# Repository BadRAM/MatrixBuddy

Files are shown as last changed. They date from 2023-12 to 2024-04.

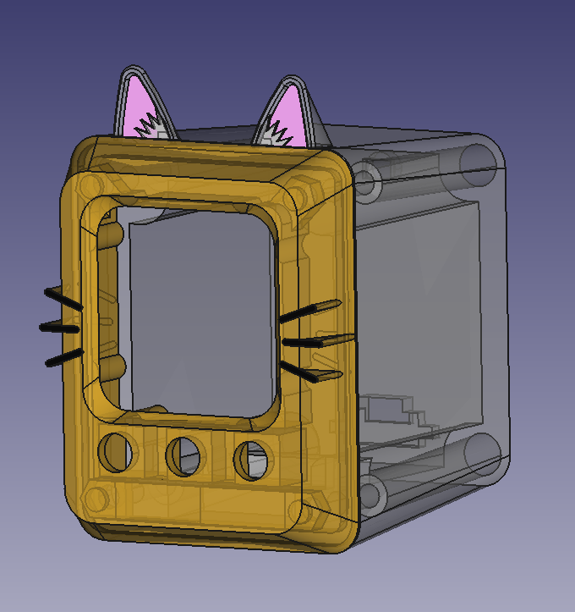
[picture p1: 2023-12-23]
Printing/MatrixBuddyCAD.png

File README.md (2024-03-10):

A friend shaped device, using a MAX7219 driven LED matrix.

[Video Demonstration](https://www.youtube.com/watch?v=6w6y-6xS34Q)

Features:
 - Matrix Buddy posesses the GREAT EMOTIONAL STRENGTH to grin through any mood, should you need TOTAL AFFIRMATION. Press the bell to toggle, Buddy will wink to acknowledge, or blink when it is released.
 - Worried about light pollution? Matrix Buddy can read the room! Sleep mode activates in near darkness. Press the left paw to configure it's light threshold. The light sensor is on the back, make sure it's not covered.
 - Not light polluted enough? Press the right paw to configure brightness. Unleash the power of the sun!
 - Connect to a computer using the bridge program and matrix buddy can mouth along to your apps. Give a face to that cameras-off zoom call!

 To set up the Matrix Buddy Bridge app, you will first need to install the included serial drivers (CM212364_Setup.exe) and restart your computer. Run MatrixBuddyBridge.exe and press "Scan", if a device is found, you're ready, just uncheck "Mute" when you're ready for the buddy to start.

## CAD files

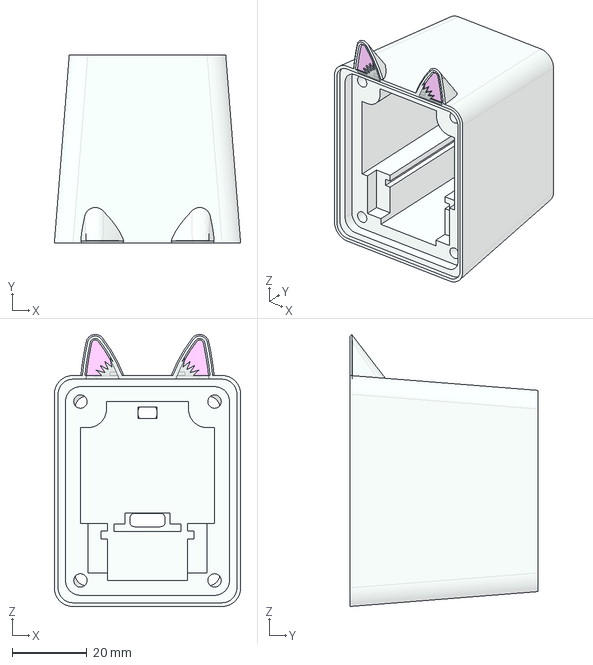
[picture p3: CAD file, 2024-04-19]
Printing/MatrixBuddy-Shell.step
50.0 x 50.5 x 73.0 mm
EarColor001
Main002

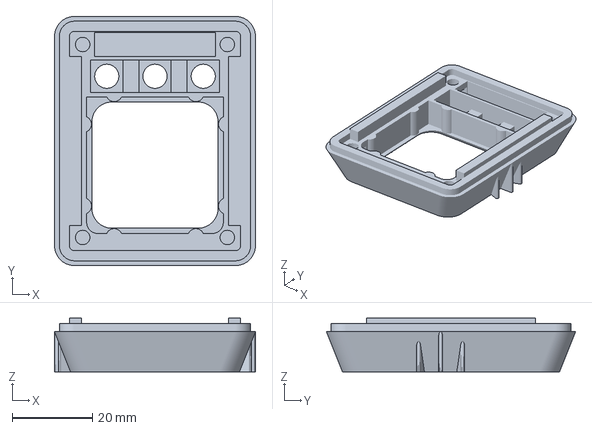
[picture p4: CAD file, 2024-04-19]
Printing/MatrixBuddyFace.3mf
50.0 x 62.0 x 13.4 mm

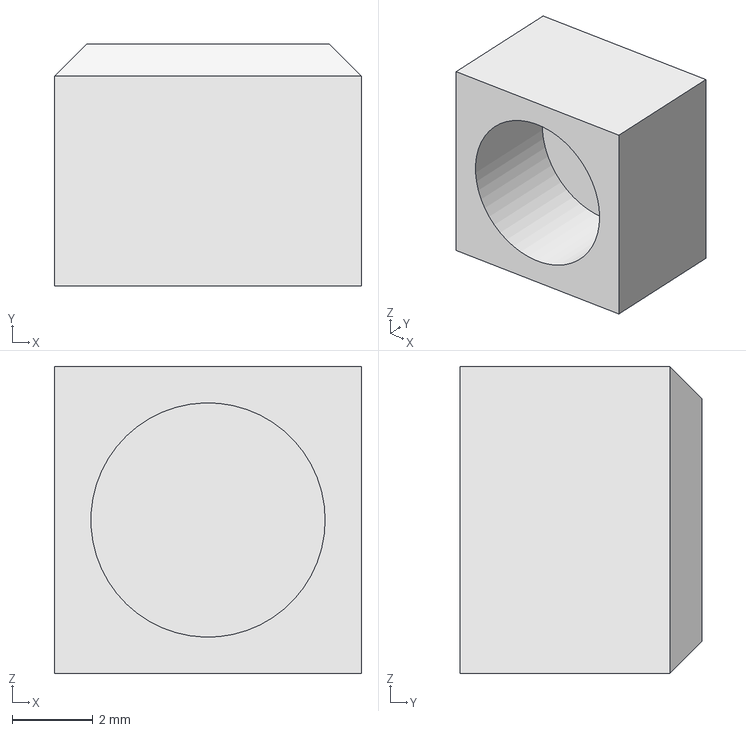
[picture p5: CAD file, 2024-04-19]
Printing/MatrixBuddy-ButtonBack.step
7.60 x 6.00 x 7.60 mm

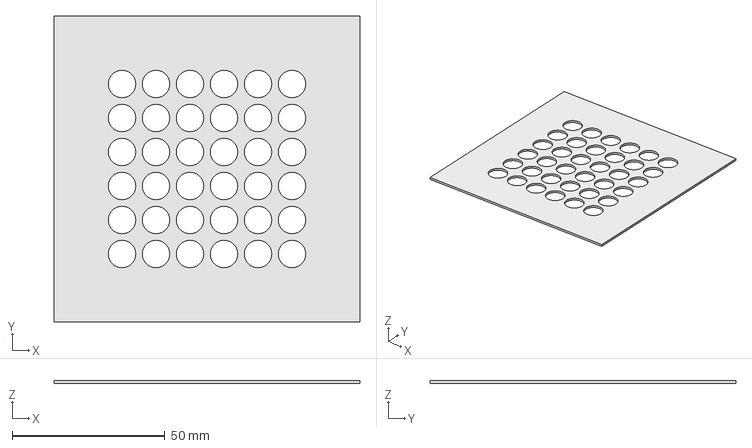
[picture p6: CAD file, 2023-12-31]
Printing/MatrixBuddy-BoxStencilCirclesStencil.step
100.0 x 100.0 x 1.00 mm

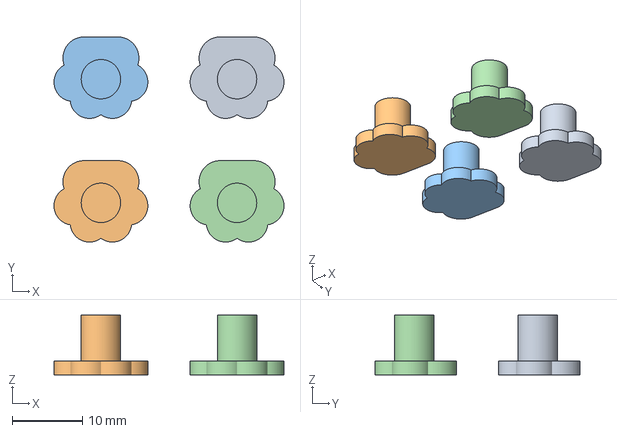
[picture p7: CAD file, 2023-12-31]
Printing/MatrixBuddyPaws.3mf
32.7 x 29.1 x 8.50 mm

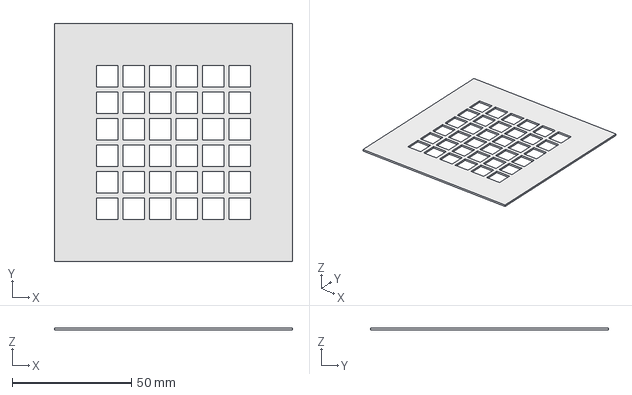
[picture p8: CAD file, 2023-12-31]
Printing/MatrixBuddy-BoxStencilSquareStencil.step
100.0 x 100.0 x 1.00 mm

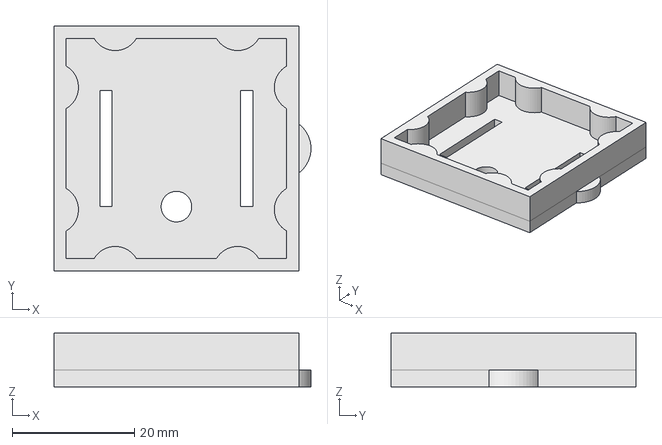
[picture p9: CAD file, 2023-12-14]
Printing/MatrixBuddy-ClippingJig.step
42.0 x 40.0 x 8.80 mm

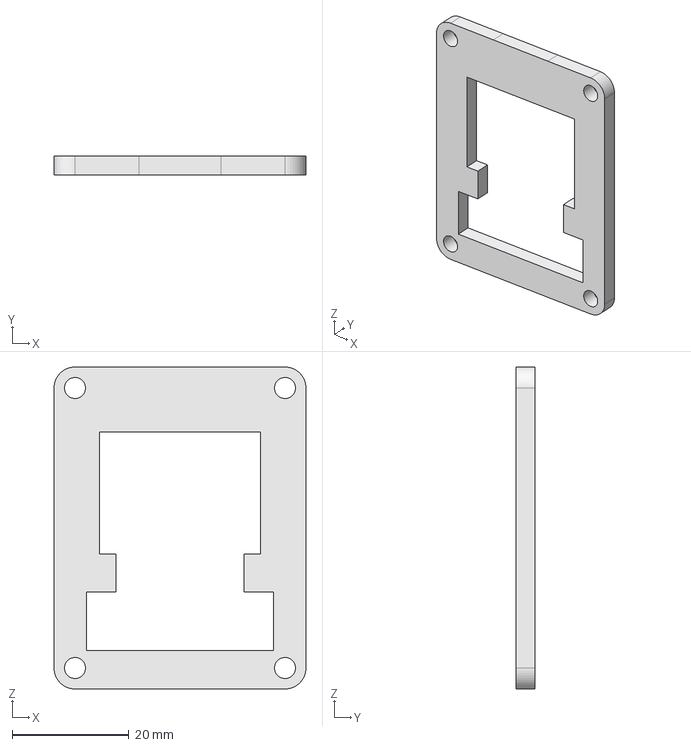
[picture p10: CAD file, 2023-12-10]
Printing/MatrixBuddy-FacerSpacer.step
43.2 x 3.20 x 55.2 mm

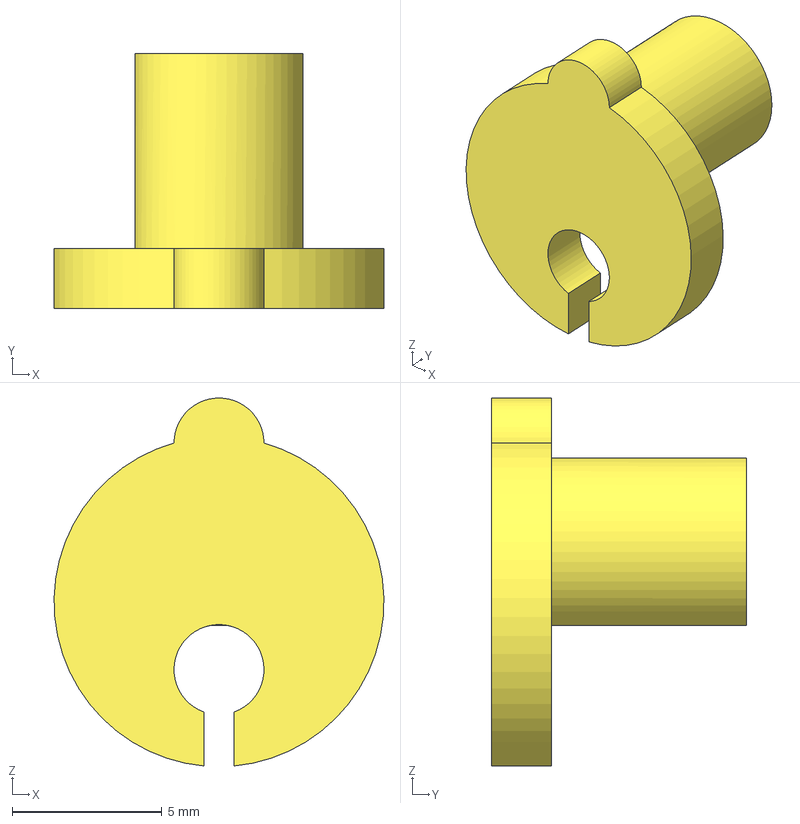
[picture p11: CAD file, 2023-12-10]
Printing/MatrixBuddy-ButtonBell.step
11.0 x 8.50 x 12.3 mm

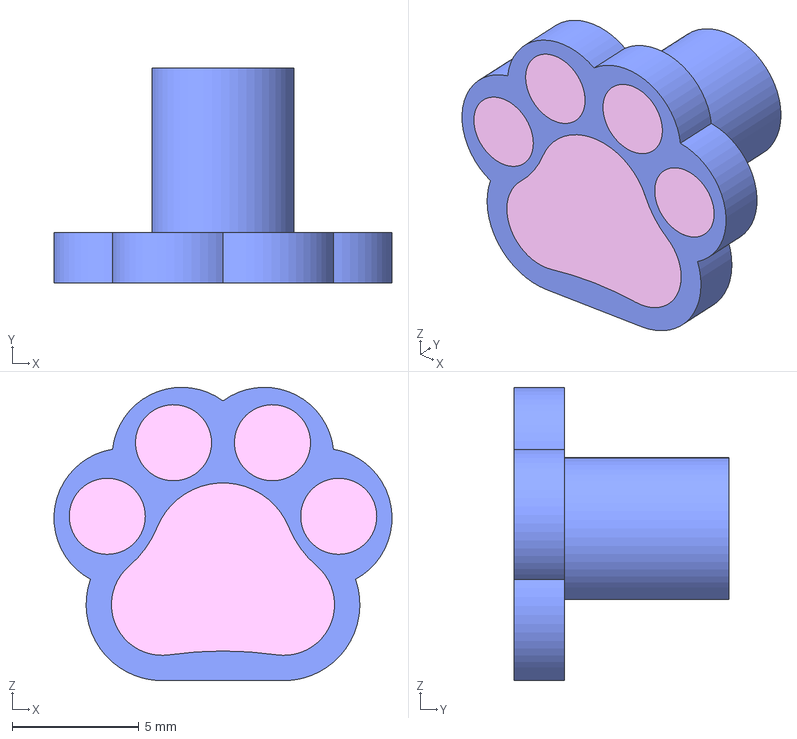
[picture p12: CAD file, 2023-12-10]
Printing/MatrixBuddy-ButtonPaw.step
13.3 x 8.50 x 11.6 mm
Button
Beans001

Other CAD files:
Printing/MatrixBuddy-FrontPanel.step
Printing/MatrixBuddy-ButtonBell.3mf
Printing/MatrixBuddyShell.3mf

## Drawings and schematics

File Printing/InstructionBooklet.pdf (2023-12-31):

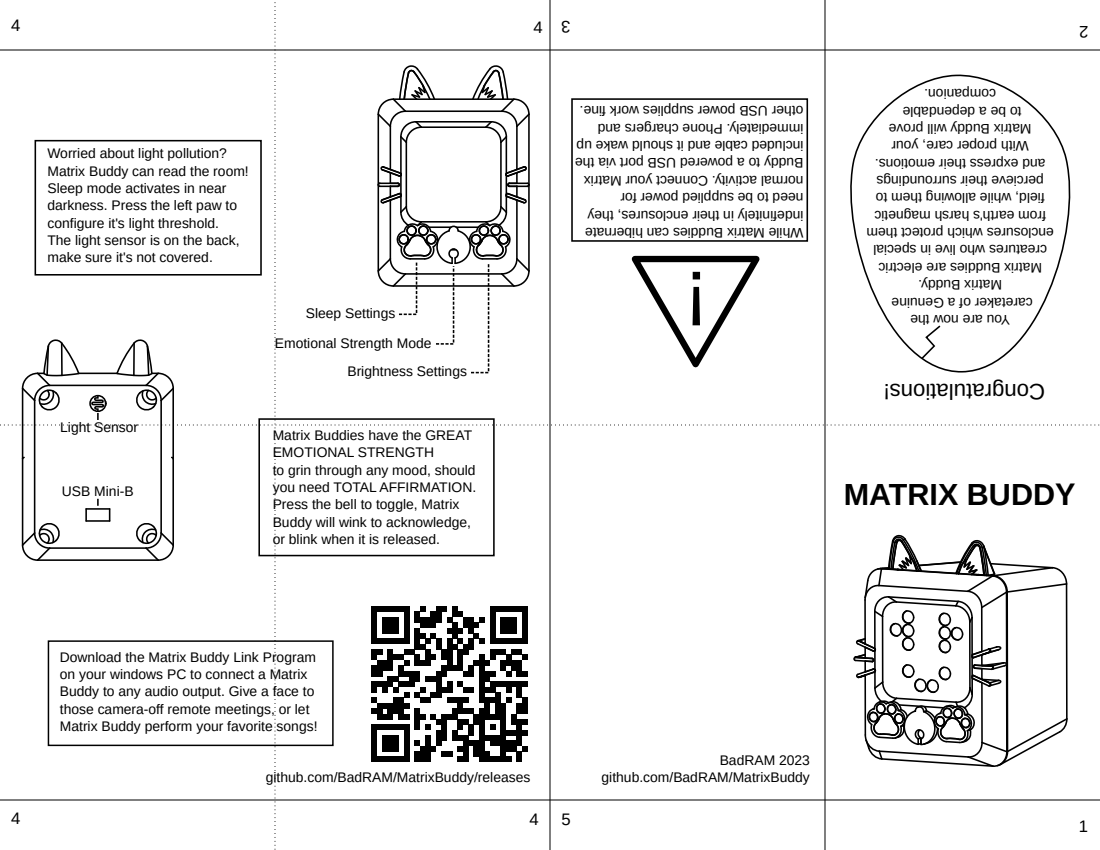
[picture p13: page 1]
BadRAM 2023; Light Sensor; USB Mini-B; Sleep Settings; Brightness Settings; MATRIX BUDDY

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

Emotional Strength Mode

Matrix Buddies have the GREAT
EMOTIONAL STRENGTH
to grin through any mood, should
you need TOTAL AFFIRMATION.
Press the bell to toggle, Matrix
Buddy will wink to acknowledge,
or blink when it is released.

Download the Matrix Buddy Link Program
on your windows PC to connect a Matrix
Buddy to any audio output. Give a face to
those camera-off remote meetings, or let
Matrix Buddy perform your favorite songs!

github.com/BadRAM/MatrixBuddy/releases

github.com/BadRAM/MatrixBuddy

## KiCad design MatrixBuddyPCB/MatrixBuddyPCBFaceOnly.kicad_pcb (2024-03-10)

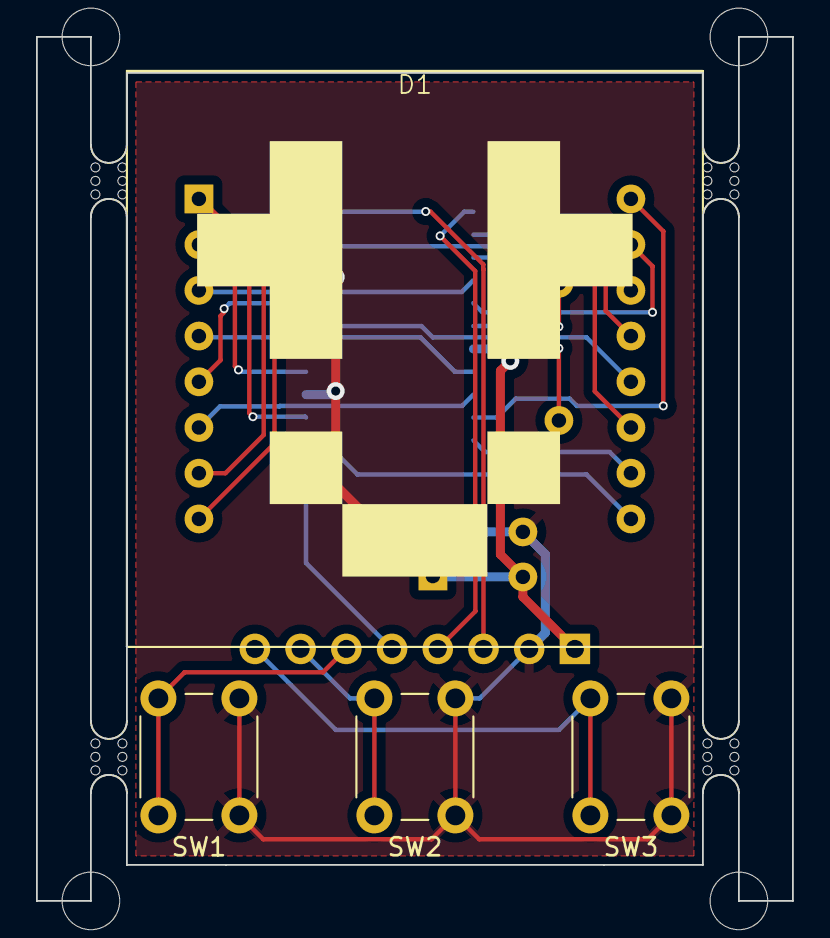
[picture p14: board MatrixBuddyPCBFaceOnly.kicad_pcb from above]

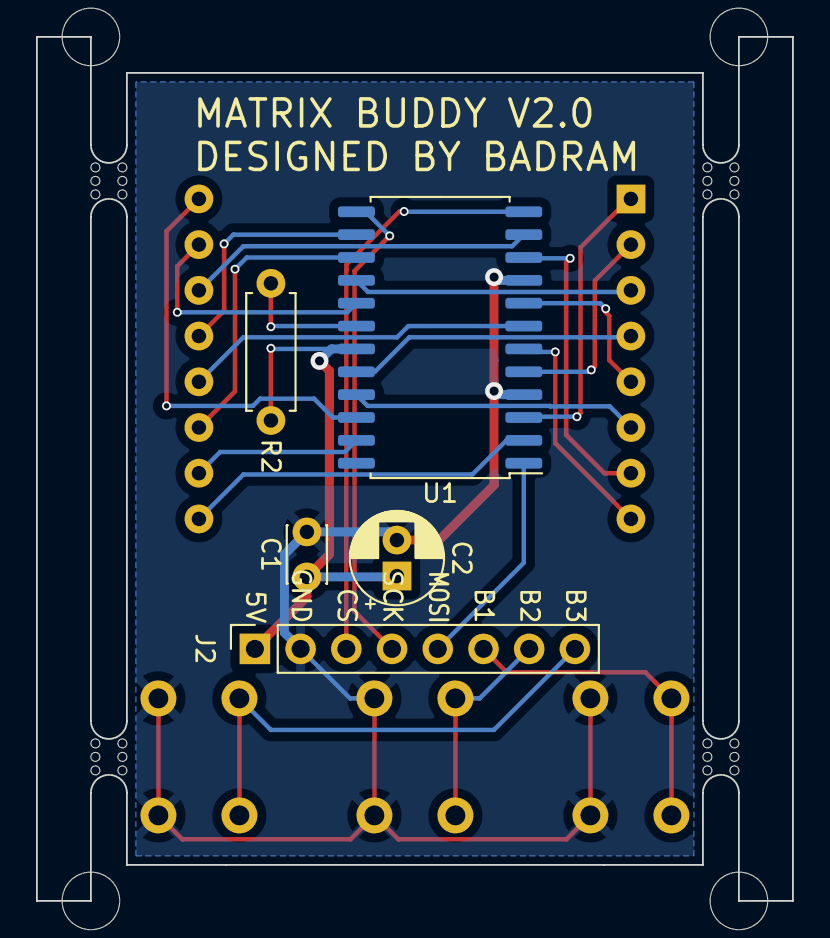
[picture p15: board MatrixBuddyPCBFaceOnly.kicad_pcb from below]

Board: 2 copper layers, 42.0 x 48.0 mm, 13 parts (5 on the bottom side), 25 nets.

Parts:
C1: 0.1uF; C_Disc_D3.0mm_W2.0mm_P2.50mm
C2: 10uF; CP_Radial_D5.0mm_P2.00mm
D1: 8x8 LED Matrix
J2: Conn_01x08_Socket; PinSocket_1x08_P2.54mm_Vertical
R2: 47K; R_Axial_DIN0207_L6.3mm_D2.5mm_P7.62mm_Horizontal
SW1, SW2, SW3: SW_Push; SW_PUSH_6mm
U1: MAX7221xWG; SOIC-24W_7.5x15.4mm_P1.27mm
mouse-bite-2mm-slot, mouse-bite-2mm-slot#2, mouse-bite-2mm-slot#3, mouse-bite-2mm-slot#4: VAL**; mouse-bite-2mm-slot

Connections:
+5V: C1.1, C2.1, J2.1, R2.1, U1.19 (V+)
COL1: D1.13 (Col1), U1.14 (SEG_A)
COL2: D1.3 (Col2), U1.16 (SEG_B)
COL3: D1.4 (Col3), U1.20 (SEG_C)
COL4: D1.10 (Col4), U1.23 (SEG_D)
COL5: D1.6 (Col5), U1.21 (SEG_E)
COL6: D1.11 (Row6), U1.15 (SEG_F)
COL7: D1.15 (Col7), U1.17 (SEG_G)
COL8: D1.16 (Col8), U1.22 (SEG_DP)
Earth: C1.2, C2.2, J2.2, SW1.2, SW2.2, SW3.2, U1.4 (GND), U1.9 (GND)
unnamed: J2.3, U1.12 (~CS)
unnamed: J2.4, U1.13 (CLK)
unnamed: J2.5, U1.1 (DIN)
unnamed: J2.6, SW1.1
unnamed: J2.7, SW2.1
unnamed: J2.8, SW3.1
unnamed: R2.2, U1.18 (ISET)
ROW1: D1.9 (Row1), U1.2 (DIG_0)
ROW2: D1.14 (Row2), U1.11 (DIG_1)
ROW3: D1.8 (Row3), U1.6 (DIG_2)
ROW4: D1.12 (Row4), U1.7 (DIG_3)
ROW5: D1.1 (Row5), U1.3 (DIG_4)
ROW6: D1.7 (Col6), U1.10 (DIG_5)
ROW7: D1.2 (Row7), U1.5 (DIG_6)
ROW8: D1.5 (Row8), U1.8 (DIG_7)

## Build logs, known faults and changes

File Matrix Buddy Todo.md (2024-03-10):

Matrix Buddy Todo
 - ~~PCB~~
  - ~~Silkscreen~~
  - ~~Routing~~
  - ~~Panelization~~

 - Begin order
  - ~~Choose order qty~~ - 10
  - ~~JLC
   - ~~Bundle with Puzzle box proto pcbs, (Codex backer, new ring, and motherboard)~~
    - ~~Codex Backboard~~
     - ~~Upper~~
     - ~~Lower~~
    - ~~New Ring boards~~
    - ~~Motherboard~~
    - ~~MX5x board for circle buttons~~
  - ~~LCSC~~
   - ~~Bundle with relays for puzzle box~~
  - ~~Digikey~~
  - ~~Adafruit (skip this time, use existing stock.)~~
  - 
 - Manufacturing
  - ~~First test assembly~~
  - ~~New shell~~
  - ~~Firmware rewrite~~
  - Batch assembly of remaining backorder
 - Marketing
  - Produce marketing images once bulk order has been assembled.
  - Create account for commissions
  - Figure out how to ship reliably to strangers
  - Get money

Connections between controller and face:
 - 5V
 - GND
 - CS - Necessary :(
 - SCK
 - COPI
 - BUTTON1
 - BUTTON2
 - BUTTON3

Dimensions:
 Case interior depth: 47.5
 face board + LED thickness: 13.2 - 1.6 = 11.6

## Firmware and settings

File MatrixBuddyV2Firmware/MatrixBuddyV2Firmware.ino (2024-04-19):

#include <FlashStorage_SAMD.h>
#include "LedControl.h"
#include "SpriteData.h"

#define LIGHT 0

#define BUTT1 1
#define BUTT2 2
#define BUTT3 3

#define EVENTQUEUELEN 64

int DIN = 9;
int CS = 10;
int CLK  = 8;
LedControl lc=LedControl(DIN, CLK, CS, 1);

unsigned int Butt1Hist = 0;
unsigned int Butt2Hist = 0;
unsigned int Butt3Hist = 0;

unsigned long LastButtonPress = 0;

// animEvents contain a function pointer, an argument pointer, and 
// a delay. arugmentless functions may be called by casting them
// to the expected type and setting arg to null.
struct animEvent
{
  void (*func)(int*);
  int (*arg)[4];
  unsigned long delay;
};

int nextEvent = 0; // the event that's going to happen next
int lastEvent = 0; // the last event in the queue
struct animEvent events[EVENTQUEUELEN];

// the millis() time of the last event's completion
unsigned long prevEvent = 0;

unsigned long LastAction = 0;
int ActionInterval = 2000;
unsigned long LastFrame = 0;
int FrameInterval = 10;

int LightLevel = 512;
unsigned long LightWatchdog = 0;

byte Brightness = 0;
byte BrightnessAddr = 1;
const int SleepThreshValues[16] = 
{
  512, 1024, 1536, 2048, 
  2560, 3072, 3328, 3584, 
  3712, 3840, 3904, 3968, 
  4032, 4064, 4080, 4096
};
byte SleepThresh = 8;
byte SleepThreshAddr = 2;
byte WakeThresh = 6;
byte WakeThreshAddr = 3;
bool StrongMode = false;
byte StrongModeAddr = 4;

bool Happy = true;

bool BridgeActive = false;
unsigned long LastBridgeMessage = 0;
unsigned long LastBridgeEyeClose = 0;
bool SingMode = false;

int (*CurrentEyes)[4];
int (*CurrentMouth)[4];

byte FrameBuffer[8] = {0,0,0,0,0,0,0,0};
// {
//   0b11110011,
//   0b10000001,
//   0b00011001,
//   0b00111101,
//   0b10011000,
//   0b10011000,
//   0b10000001,
//   0b11001111,
// };

void drawEyes(int eyes[4])
{
  for(int i=0;i<4;i++) FrameBuffer[i] = eyes[i];
  updateDisplay();
}

void drawMouth(int mouth[4])
{
  for(int i=4;i<8;i++) FrameBuffer[i] = mouth[i-4];
  updateDisplay();
}

// rotate and flip the display buffer while outputting it as setrow instructions.
void updateDisplay()
{
  byte OutputBuffer[8] = {0, 0, 0, 0, 0, 0, 0, 0};

  for (int x=0; x<8; x++)
  {
    for (int y=0; y<8; y++)
    {
      OutputBuffer[x] |= ((FrameBuffer[(14-y)%8] >> x) & 1) << y;
    }
  }
  lc.setRow(0, 0, OutputBuffer[0]);
  lc.setRow(0, 1, OutputBuffer[1]);
  lc.setRow(0, 2, OutputBuffer[2]);
  lc.setRow(0, 3, OutputBuffer[3]);
  lc.setRow(0, 4, OutputBuffer[4]);
  lc.setRow(0, 5, OutputBuffer[5]);
  lc.setRow(0, 6, OutputBuffer[6]);
  lc.setRow(0, 7, OutputBuffer[7]);
}

void clearDisplay()
{
  lc.clearDisplay(0);
  for (int i=0; i<8; i++)
  {
    FrameBuffer[i] = 0;
  }
}

void addEvent(void (*func)(int*), int (*arg)[4], unsigned long delay)
{
  if (events[nextEvent].func == NULL)
  {
    lastEvent = nextEvent;
    prevEvent = millis();
  }
  else
  {
    // increment lastEvent, with guard against overrun.
    int e = (lastEvent + 1) % EVENTQUEUELEN;
    if (e == nextEvent)
    {
      // Serial.println("event queue overrun!");
      return;
    }
    lastEvent = e;
  }

  events[lastEvent].func = func;
  events[lastEvent].arg = arg;
  events[lastEvent].delay = delay;
}

void closeEyes()
{
  addEvent(&drawEyes, &Blink1, 0);
  addEvent(&drawEyes, &Blink2, 50);
  addEvent(&drawEyes, &Blink2, 50);
}

void openEyes()
{
  addEvent(&drawEyes, &Blink2, 0);
  addEvent(&drawEyes, &Blink1, 50);
  addEvent(&drawEyes, CurrentEyes, 50);
}

void blink()
{
  // Serial.println("blink");
  addEvent(&drawEyes, &Blink1, 0);
  addEvent(&drawEyes, &Blink2, 50);
  addEvent(&drawEyes, &Blink1, 100);
  addEvent(&drawEyes, CurrentEyes, 100);
}

void wink()
{
  // Serial.println("wink");
  addEvent(&drawEyes, &Wink1, 0);
  addEvent(&drawEyes, &Wink2, 50);
  addEvent(&drawEyes, &Wink1, 300);
  addEvent(&drawEyes, CurrentEyes, 50);
}

void yawn()
{
  //Serial.println("yawn");
  addEvent(&drawMouth, &Yawn1,  0);
  addEvent(&drawMouth, &Yawn2,  100);
  addEvent(&drawEyes,  &Squint, 100);
  addEvent(&drawMouth, &Yawn3,  0);
  addEvent(&drawMouth, &Yawn4,  100);
  addEvent(&drawMouth, &Yawn3,  2000);
  addEvent(&drawMouth, &Yawn4,  200);
  addEvent(&drawMouth, &Yawn3,  200);
  addEvent(&drawMouth, &Yawn2,  100);
  addEvent(&drawMouth, &Yawn1,  100);
  addEvent(&drawEyes, CurrentEyes,  0);
  addEvent(&drawMouth, CurrentMouth,  100);
  addEvent(&drawEyes, CurrentEyes, 50);
  blink();
  blink();
}

void updateLightLevel()
{
  // Manually read ADC
  ADC->SWTRIG.bit.START = 1;                       // Initiate a software trigger to start an ADC conversion
  while(ADC->STATUS.bit.SYNCBUSY);                 // Wait for write synchronization
  while(!ADC->INTFLAG.bit.RESRDY);                 // Wait for the conversion to complete
  ADC->INTFLAG.bit.RESRDY = 1;                     // Clear the result ready (RESRDY) interrupt flag
  while(ADC->STATUS.bit.SYNCBUSY);                 // Wait for read synchronization
  int result = ADC->RESULT.reg;                    // Read the ADC result
  
  LightLevel = (LightLevel + result) / 2;
}

void sleep()
{
  CurrentMouth = &Smile;
  yawn();
  finishEvents();
  updateLightLevel();
  delay(100);
  updateLightLevel();
  delay(100);
  updateLightLevel();
  delay(100);
  updateLightLevel();
  if (LightLevel < SleepThreshValues[SleepThresh])
  {
    return;
  }
  delay(200);
  drawEyes(Blink1);
  delay(250);
  drawMouth(SleepMouth);
  delay(250);
  drawEyes(Blink2);
  delay(2000);
  clearDisplay();
  unsigned long litSince = 0;
  while (true)
  {
    updateLightLevel();
    updateButtons();

    if (LightLevel < SleepThreshValues[WakeThresh])
    {
      if (litSince == 0)
      {
        litSince = millis();
      }
      else if (millis() - litSince >= 4000)
      {
        break;
      }
    }
    else
    {
      litSince = 0;
    }

    if (buttonPressed(&Butt1Hist))
    {
      sleepThreshConfig(false);
    }

    // Serial.print("litSince: ");
    // Serial.print(litSince);
    // Serial.print(", Lightlevel: ");
    // Serial.println(LightLevel);
    delay(500);
  }
  delay(1000);
  drawEyes(Blink2);
  drawMouth(SleepMouth);
  delay(500);
  drawEyes(Blink1);
  delay(500);
  CurrentMouth = &Smile;
  Happy = true;
  drawMouth(Smile);
  yawn();

  // prevent instant random action
  LastAction = millis();
}

void drawBarDisplay(int row, byte val)
{
  byte e = (8 - (val + 1 +(millis() % 200 > 100)) / 2);
  lc.setRow(0, 7 - row, 0xFF >> e + 1 | ((e > 7 ? 0 : 1) << 7));
}

void screenBrightnessConfig()
{
  clearEvents();
  drawEyes(*CurrentEyes);
  drawMouth(*CurrentMouth);
  closeEyes();
  finishEvents();
  updateButtons();
  clearDisplay();
  drawEyes(BrightnessIcon);

  while (!buttonPressed(&Butt2Hist))
  {
    drawBarDisplay(6, Brightness);

    delay(5);
    updateButtons();

    if (buttonPressed(&Butt1Hist) && Brightness != 0) Brightness--;
    if (buttonPressed(&Butt3Hist) && Brightness != 15) Brightness++;
    Brightness = constrain(Brightness, 0, 15);

    lc.setIntensity(0, Brightness);
  }

  EEPROM.write(BrightnessAddr, Brightness);
  EEPROM.commit();
  // Serial.println(EEPROM.read(BrightnessAddr));

  drawMouth(*CurrentMouth);
  openEyes();
  finishEvents();

  // prevent instant random action
  LastAction = millis();
}

void sleepThreshConfig(bool anim)
{
  if (anim)
  {
    clearEvents();
    drawEyes(*CurrentEyes);
    drawMouth(*CurrentMouth);
    closeEyes();
    finishEvents();
  }

  updateButtons();
  clearDisplay();
  drawEyes(SleepThreshIcon);

  while (!buttonPressed(&Butt2Hist))
  {
    // byte e = (7 - (SleepThresh + 1) / 2);
    // e = (((SleepThresh % 2) * 2) + 1) << e;
    // lc.setRow(0, 6, e);

    updateLightLevel();
    for (int i = 15; i >= 0; i--)
    {
      if (LightLevel > SleepThreshValues[i])
      {
        drawBarDisplay(5, i);
        break;
      }
    }

    drawBarDisplay(6, SleepThresh);
    drawBarDisplay(7, WakeThresh);

    delay(5);
    updateButtons();

    if (buttonPressed(&Butt1Hist) && SleepThresh != 0) SleepThresh--;
    if (buttonPressed(&Butt3Hist) && SleepThresh != 15) SleepThresh++;
    SleepThresh = constrain(SleepThresh, 0, 15);
    WakeThresh = SleepThresh - min(2, SleepThresh);

    // Serial.print("SleepThresh: ");
    // Serial.println(SleepThresh);
  }

  EEPROM.write(SleepThreshAddr, SleepThresh);
  EEPROM.write(WakeThreshAddr, WakeThresh);
  EEPROM.commit();
  // Serial.println(EEPROM.read(SleepThreshAddr));

  if (anim)
  {
    drawMouth(*CurrentMouth);
    openEyes();
    finishEvents();
  }
  else
  {
    clearDisplay();
  }

  // prevent instant random action
  LastAction = millis();
}

void toggleStrongMode()
{
  finishEvents();

  if (!StrongMode)
  {
    Happy = true;
    CurrentMouth = &Smile;
    drawMouth(*CurrentMouth);
    StrongMode = true;
    wink();
  }
  else
  {
    Happy = true;
    CurrentMouth = &Mischief;
    drawMouth(*CurrentMouth);
    StrongMode = false;
    blink();
  }

  EEPROM.write(StrongModeAddr, StrongMode);
  EEPROM.commit();

  // prevent instant random action
  LastAction = millis();
}

void randomAction()
{
  int roll = random(1, 100);

  // if(digitalRead(BUTT1) == LOW) roll = 1;
  // if(digitalRead(BUTT2) == LOW) roll = 2;
  // if(digitalRead(BUTT3) == LOW) roll = 3;

  if (roll == 1 && Happy == true)
  {
    addEvent(&drawMouth, &Cat, 0);
    addEvent(&drawMouth, CurrentMouth, 2000);
  }
  else if (roll == 2)
  {
    yawn();
  }
  else if (roll == 3)
  {
    CurrentMouth = &Smile;
    Happy = true;
    drawMouth(*CurrentMouth);
  }
  else if (roll < 15) // change mood
  {
    int mood = 2;

    if (CurrentMouth == &Pout)
    {
      mood = random(4, 6);
    }
    else if (CurrentMouth == &Neutral || CurrentMouth == &Uncertain)
    {
      mood = random(2, 7);
    }
    else if (CurrentMouth == &Smile)
    {
      mood = random(1, 6);
    }

    if (StrongMode && mood >= 4)
    {
      mood = 3;
    }

    switch (mood)
    {
      case 1:
        CurrentMouth = &Mischief;
        Happy = true;
        break;
      case 2:
        CurrentMouth = &Smile;
        Happy = true;
        break;
      case 3:
        CurrentMouth = &Smile;
        Happy = true;
        break;
      case 4:
        CurrentMouth = &Neutral;
        Happy = false;
        break;
      case 5:
        CurrentMouth = &Uncertain;
        Happy = false;
        break;
      case 6:
        CurrentMouth = &Pout;
        Happy = false;
        break;
    }
  }
  else if (roll < 35) // Look in random direction
  {
    switch (random(1,4))
    {
      case 1:
        drawEyes(LookLeft);
        break;
      case 2:
        drawEyes(LookUp);
        break;
      case 3:
        drawEyes(LookRight);
        break;
      default:
        drawEyes(LookUp);
        break;
    }
    //delay(random(500, 2000));
    addEvent(&drawEyes, CurrentEyes, random(500, 2000));
  }
  else if (roll < 45) // Emotion event. Wink if happy, squint if not.
  {
    if (Happy)
    {
      wink();
    }
    else
    {
      drawEyes(Squint);
      addEvent(&drawEyes, CurrentEyes, random(800, 4000));
      // delay(random(800, 4000));
    }
  }
  else // blink most of the time
  {
    blink();
    while(random(1, 6) == 1)
    {
      addEvent(&drawEyes, CurrentEyes, 50);
      blink();
    }
  }
}

void updateEvents()
{
  // abort if no events.
  if (events[nextEvent].func == NULL) return;

  if (millis() - prevEvent >= events[nextEvent].delay)
  {
    // Serial.print("event time, nextEvent: ");
    // Serial.print(nextEvent);
    // Serial.print(" delay: ");
    // Serial.print(events[nextEvent].delay);
    // Serial.print(" mil since lE: ");
    // Serial.print(millis() - prevEvent);
    // Serial.print(" lastEvent: ");
    // Serial.print(lastEvent);
    // Serial.print(" - ");

    // do event
    if (events[nextEvent].arg == NULL)
    {
      // Serial.println("Called Event()");
      ((void*)*events[nextEvent].func);
    }
    else
    {
      // Serial.println("Called Event(arg)");
      (*events[nextEvent].func)(*events[nextEvent].arg);
    }

    // clear event
    events[nextEvent].func = 0;
    events[nextEvent].arg = 0;
    events[nextEvent].delay = 0;

    // increment nextEvent
    nextEvent++;
    nextEvent = nextEvent % EVENTQUEUELEN;

    // update prevEvent
    prevEvent = millis();
  }
  else
  {
    //Serial.print(".");
  }
}

void finishEvents()
{
  while (events[nextEvent].func != NULL)
  {
    updateEvents();
    delay(1);
  }
}

void clearEvents()
{
  for (int i = 0; i < EVENTQUEUELEN; i++)
  {
    events[i].func = 0;
    events[i].arg = 0;
    events[i].delay = 0;
  }

  nextEvent = 0;
  lastEvent = 0;
}

void updateButton(int button, unsigned int* history)
{
  *history = *history << 1;
  *history |= digitalRead(button);
}

void updateButtons()
{
  updateButton(BUTT1, &Butt1Hist);
  updateButton(BUTT2, &Butt2Hist);
  updateButton(BUTT3, &Butt3Hist);
  if (buttonPressed(&Butt1Hist) || 
      buttonPressed(&Butt2Hist) || 
      buttonPressed(&Butt3Hist))
  {
    LastButtonPress = millis();
  }
}

bool buttonPressed(unsigned int* history)
{
  return (*history & 0xFF) == 0xFE;
}

void setup()
{
  Serial.begin(57600);

  //while(!Serial);                               // Wait for the console to open

  //Serial.println("SERIAL ONLINE");

  Brightness = EEPROM.read(BrightnessAddr);
  if (Brightness == 255) Brightness = 0;
  SleepThresh = EEPROM.read(SleepThreshAddr);
  if (SleepThresh == 255) SleepThresh = 8;
  WakeThresh = EEPROM.read(WakeThreshAddr);
  if (WakeThresh == 255) WakeThresh = 6;
  StrongMode = EEPROM.read(StrongModeAddr);
  if (StrongMode == 255) StrongMode = 0;

  lc.shutdown(0,false);
  lc.setIntensity(0, Brightness);
  lc.clearDisplay(0);

  pinMode(BUTT1, INPUT_PULLUP);
  pinMode(BUTT2, INPUT_PULLUP);
  pinMode(BUTT3, INPUT_PULLUP);

  //Serial.println("Initializing ADC");

  // Manually configure ADC for light sensor
  pinMode(LIGHT, INPUT_PULLUP);
  ADC->CTRLB.reg = ADC_CTRLB_PRESCALER_DIV512 |    // Divide Clock ADC GCLK by 512 (48MHz/512 = 93.7kHz)
                   ADC_CTRLB_RESSEL_12BIT;         // Set ADC resolution to 12 bits
  while(ADC->STATUS.bit.SYNCBUSY);                 // Wait for synchronization
  ADC->SAMPCTRL.reg = 0x08;                        // Set max Sampling Time Length to half divided ADC clock pulse times SAMPCTRL (341.33us)
  ADC->INPUTCTRL.bit.MUXPOS = 0x0;                 // Set the analog input to A0
  while(ADC->STATUS.bit.SYNCBUSY);                 // Wait for synchronization
  ADC->CTRLA.bit.ENABLE = 1;                       // Enable the ADC
  while(ADC->STATUS.bit.SYNCBUSY);                 // Wait for synchronization

  //Serial.println("ADC ONLINE");

  updateLightLevel();
  randomSeed(LightLevel);

  //Serial.println("SEED SET");

  CurrentEyes = &Eyes;
  CurrentMouth = &Smile;

  drawEyes(Blink2);
  delay(200);
  drawMouth(SleepMouth);
  drawEyes(Blink1);
  delay(200);
  drawEyes(*CurrentEyes);
  drawMouth(*CurrentMouth);
  delay(500);
}

void loop()
{
  // Serial.print("Butt1: ");
  // Serial.print(Butt1Hist, BIN);
  // Serial.print(" Butt2: ");
  // Serial.print(Butt2Hist, BIN);
  // Serial.print(" Butt3: ");
  // Serial.print(Butt3Hist, BIN);
  // Serial.print(" LightSensor: ");
  // Serial.println(digitalRead(LIGHT));

  updateButtons();

  // update light level and check if sleepy time
  updateLightLevel();
  if (LightLevel >= SleepThreshValues[SleepThresh])
  {
    sleep();
    return;
  }

  //Serial.println(Butt1Hist, BIN);
  // Check for button presses
  if(buttonPressed(&Butt1Hist))
  {
    //Serial.println("Butt 1 pressed");
    sleepThreshConfig(true);
    return;
  }

  // Check for button presses
  if(buttonPressed(&Butt2Hist))
  {
    //Serial.println("Butt 2 pressed");
    toggleStrongMode();
    return;
  }

  // Check for button presses
  if(buttonPressed(&Butt3Hist))
  {
    //Serial.println("Butt 3 pressed");
    screenBrightnessConfig();
    return;
  }

  if (BridgeActive)
  {
    if (millis() - LastBridgeMessage >= 1000)
    {
      BridgeActive = false;
      drawMouth(*CurrentMouth);
      drawEyes(*CurrentEyes);
      SingMode = false;
    }

    if (millis() - LastBridgeEyeClose >= 600)
    {
      drawEyes(*CurrentEyes);
    }
    delay(5);
    return; // early return to skip random actions
  }

  // Do random event if time is right
  if (millis() - LastAction >= ActionInterval)
  {
    randomAction();
    LastAction = millis();
    ActionInterval = random(3000, 8000);
  }

  updateEvents();

  // delay until it's time to start the next frame.
  while(millis() - LastFrame < FrameInterval)
  LastFrame = millis();
}

void serialEvent() {
  while (Serial.available()) {
    // get the new byte:
    char inChar = (char)Serial.read();

    switch (inChar)
    {
      case 's':
        // (s)can, do nothing and (a)cknowledge
        Serial.print("a"); // (a)cknowledge execution of command
        break;
      case '0':
        if (BridgeActive)
        {
          drawMouth(*CurrentMouth);
          drawEyes(*CurrentEyes);
          SingMode = false;
          BridgeActive = false;
        }
        break;
      case '1':
        SingMode = false;
        drawMouth(Talk);
        break;
      case '2':
      case '3':
        if (SingMode)
        {
          drawMouth(Sing);
          LastBridgeEyeClose = millis();
        }
        else
        {
          drawMouth(Yawn3);
        }
        break;
      case '4':
        SingMode = true;
        drawMouth(Yawn4);
        drawEyes(Squint);
        LastBridgeEyeClose = millis();
        break;
    }

    if ((inChar != 's') && (inChar != '0'))
    {
      BridgeActive = true;
      LastBridgeMessage = millis();
    }
  }
}

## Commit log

2023-11-30 CAD for shell and stls for printing
    [MatrixBuddy-ButtonBack.stl, MatrixBuddy-ButtonBell.stl, MatrixBuddy-ButtonPaw.stl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]
2023-12-02 multi material printing overhaul!
    [MatrixBuddy-ButtonBack.step, MatrixBuddy-ButtonBack.stl, MatrixBuddy-ButtonBell.stl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]
2023-12-02 ears rework
    [MatrixBuddy-ButtonBell.step, MatrixBuddy-ButtonPaw.step, MatrixBuddy-FrontPanel.step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]
2023-12-10 Refactored firmware to use non blocking animations via event queue system, added brightness setting GUI
    [MatrixBuddy-ButtonBack.step, MatrixBuddy-ButtonBell.3mf, MatrixBuddy-ButtonBell.step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]
2023-12-14 reorganized files and added Bridge app
    [MatrixBuddy-ButtonBack.step, MatrixBuddy-ButtonBell.3mf, MatrixBuddy-ButtonBell.step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]
2023-12-16 fixed ear sneeze in MatrixBuddyShell print settings
    [MatrixBuddyShell.3mf]
2023-12-16 Fixed bug where MatrixBuddyBridge would fail to detect connected buddy because of arduino's serial auto-reset feature.
    [MatrixBuddyFirmware.ino]
2023-12-31 finished instruction booklet
    [MatrixBuddy-BoxStencilCirclesStencil.step, MatrixBuddy-BoxStencilSquareStencil.step, MatrixBuddyPaws.3mf]
2024-02-08 Designed PCB for production
    [MatrixBuddyPCB.kicad_sch]
2024-02-10 pcb v2.0 final
2024-03-10 Bugfixing ahead of first production batch.
    [MatrixBuddy-FrontPanel.step, MatrixBuddy-Shell.step, MatrixBuddyPCB.kicad_sch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]
2024-04-19 fixed bug that prevented brightness and other settings from being saved between power cycles.
    [MatrixBuddy-ButtonBack.step, MatrixBuddy-FrontPanel.step, MatrixBuddy-Shell.step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]
